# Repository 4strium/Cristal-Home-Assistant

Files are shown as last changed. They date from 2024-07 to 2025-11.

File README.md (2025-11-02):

<h1 align="center">Cristal Home Assistant</h1>

<p align="center">
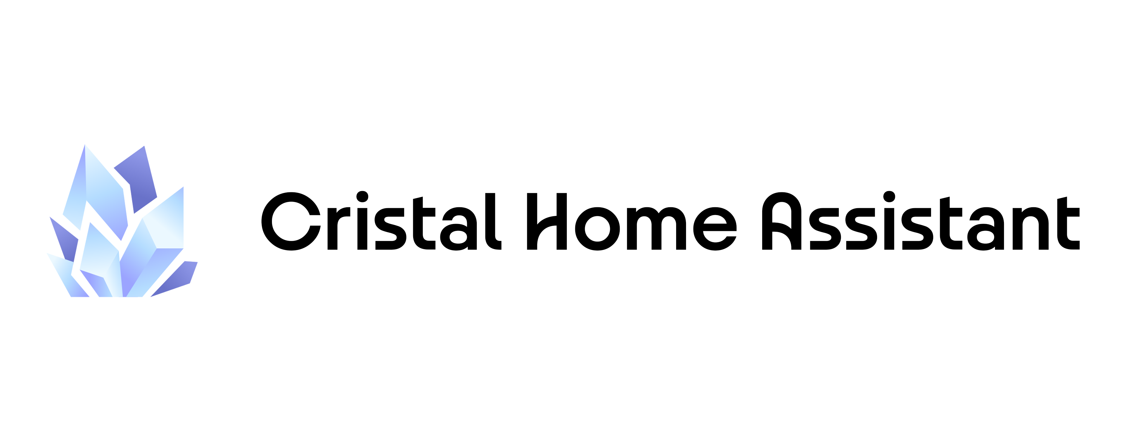
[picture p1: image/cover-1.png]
Cristal Home Assistant logo
  
</p>

## Introduction 
This personal project is based on a simple observation: nowadays there are a significant number of voice assistants coupled with numerous tools promising hyper connectivity and boosted productivity. We therefore end up getting lost in all these opaque layers processing our personal data as well as in subscriptions that are often prohibitively expensive compared to the simplicity of the tasks that we want our electronic companion to carry out.

<p align="center">
  Cristal Home Assistant
</p>

Today I decided to show you in the smallest details how I managed to design **Cristal** a voice assistant which can respond to all your wishes as long as you are ready to fiddle a minimum between the hardware and the software.

<p align="center">
  Cristal Home Assistant
</p>

## Project presentation

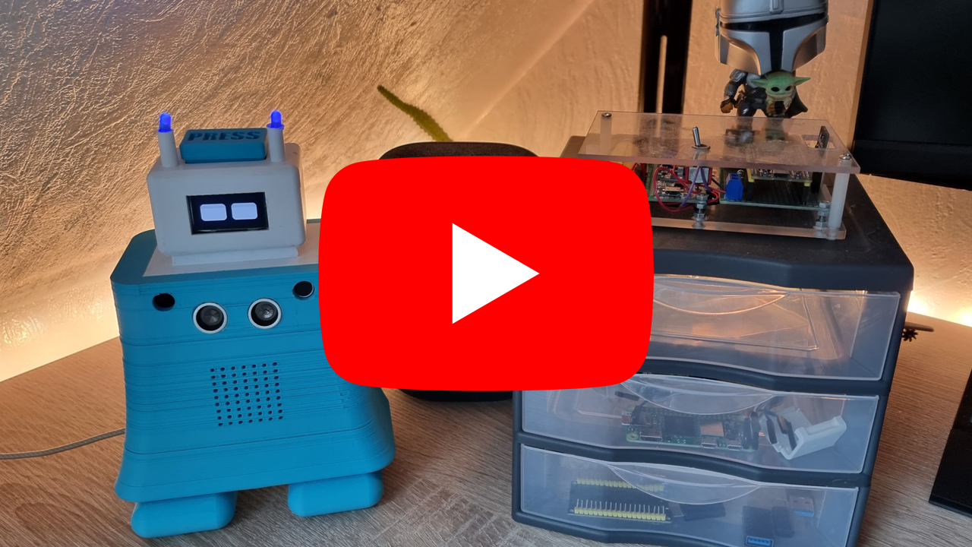
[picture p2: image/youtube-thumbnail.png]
(https://www.youtube.com/watch?v=M7OH803nQkw)


## The necessary equipment

<p align="center">
  
</p>

* An [ESP32](https://www.amazon.fr/esp32-wroom/s?k=esp32+wroom) will be the microcontroller of our project! We will take full advantage of its WiFi capacity but also of its integrated ADCs.

<p align="center">
  
</p>

* An [OLED screen (128x64) using the SH1106 chip](https://www.az-delivery.de/en/products/1-3zoll-i2c-oled-display), it will be the main means of feedback with the user.

<p align="center">
  
</p>

* A [MicroSD Card Module](https://www.amazon.fr/esp32-sd/s?k=esp32+sd) as well as a microSD card with the smallest capacity you have, in fact it will be useful to us only to temporarily store the audio file recorded by the microphone as well as the secret identifiers specific to your assistant, so it only takes a few kilobytes , but if you have personal upgrades requiring storage then judge the card's capacity accordingly. **⚠️ IMPORTANT NOTE : the card must be formatted in [FAT32 format](https://support.microsoft.com/fr-fr/topic/comment-convertir-un-lecteur-en-fat32-%C3%A0-l-aide-du-convertisseur-de-lecteur-5f751b9d-60a2-01bc-4079-2f536b876cc3)**

<p align="center">
  
</p>

*©TeachWithICT*

* An [Ultrasonic Sensor](https://www.amazon.com/ultrasonic-sensor/s?k=ultrasonic+sensor), **HC-SR04** is the safe bet.

<p align="center">
  
</p>

* A microphone using the i2s protocol, personally I use the [MAX9814](https://www.az-delivery.de/fr/products/max9814-mikrofon) which is widespread in the field of microelectronics in particular because it carries a high quality amplifier with automatic gain control (AGC) and low noise microphone polarization.

<p align="center">
  
</p>

* LED's of the color you want. *(the best is that it matches the color of your case)*

<p align="center">
  
</p>

* A [push button](https://www.amazon.fr/s?k=push+button&__mk_fr_FR=%C3%85M%C3%85%C5%BD%C3%95%C3%91&ref=nb_sb_noss). 

## A small server
Unfortunately, although the esp32 is a true marvel due to the extent of its capabilities, certain actions are either not possible, or possible but within a period of time which makes use uncomfortable and not smooth.

This is the case for voice recognition for example, which is therefore central to our project, which is why it is necessary to first record the audio file before transmitting it to a more powerful device so that the latter achieves recognition. But be careful by "more powerful" I don't mean a server with 32GB of ram and a premium CPU, no it's quite the opposite! You can either rent the smallest server configuration from a host, or use a Raspberry Pi at home.

<p align="center">
  
</p>

In my case for example, I rent a server thanks to DigitalOcean, I selected the lowest possible configuration with only 1GB of Ram and an inefficient Intel processor. But it is more than sufficient as you can see in the graphs below, in terms of the memory or processor usage percentages with actions initiated by my custom assistant.

<p align="center">
  
</p>

*Screenshot of data measured on the server I used for this project*

**If you would like to see in more detail how to set up your Linux server for the voice assistant and enable the [Google Assistant](https://assistant.google.com/intl/en_en/) SDK, [click here](https://mellaza.tech/posts/cristal-setup-server/).**

## 3D models for those who want/can print them...
You can print the four parts of the project, here are the 3d files, feel free to modify them as you wish! *(namely I printed it with my Ender-3 V3 SE)*

<p align="center">
  
</p>

* [The button to activate voice recording.](https://github.com/4strium/Cristal-Home-Assistant/blob/main/models/Bouton-Cristal-AI.3mf)
* [The head of the robot with its two antennas.](https://github.com/4strium/Cristal-Home-Assistant/blob/main/models/Head%20cristal.3mf)
* [The body that will carry all the electronics.](https://github.com/4strium/Cristal-Home-Assistant/blob/main/models/body.3mf) 
* [The hood to make the link between the head and the body.](https://github.com/4strium/Cristal-Home-Assistant/blob/main/models/capuchon.3mf)

## Wiring 

Make the connections follow this:

### Micro SD Card Module :
* 3.3 V
* MISO : GPIO 19
* CLK : GPIO 18
* MOSI : GPIO 23
* CS : GPIO 5
* GND

### Ultrasonic sensor :
* VCC : 5V
* Trig : GPIO 15
* Echo : GPIO 2
* GND

### OLED Display :
* VDD : 5V
* GND
* SCK : GPIO 22
* SDA : GPIO 27

### Blue LED'S :
* GPIO 12
* GND 

### Push Button :
* 3.3 V
* GPIO 4
* GND

### Microphone MAX9814 :
* VDD : 3.3 V
* OUT : GPIO 35 (ADC1_CHANNEL_7)
* GND

## Functionalities :

* If you want to see how to display live weather on screen via I2C, [click here](https://mellaza.tech/posts/live-weather-i2c-screen/).

* If you want to see how to display live date and time based on GPS coordinates (to get timezone) on an I2C screen, [click here](https://mellaza.tech/posts/date-time-i2c-screen/).

* If you want to see how to display daily news on screen via I2C, [click here](https://mellaza.tech/posts/live-news-i2c-screen/).

* If you want to see how to record sound on microSD card via MAX9814 microphone, [click here](https://mellaza.tech/posts/record-sound-max9814/).

* If you want to see how to keep your [API](https://en.wikipedia.org/wiki/API) identifiers secret for this ultra-connected project, [click here](https://mellaza.tech/posts/secure-credentials-esp32/).

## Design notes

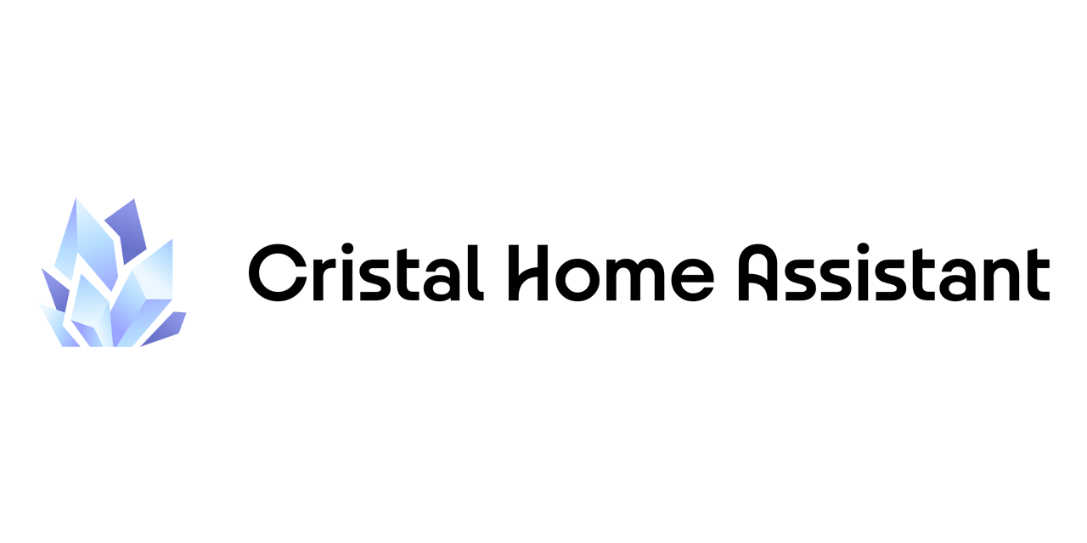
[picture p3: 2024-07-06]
image/cover-2.png

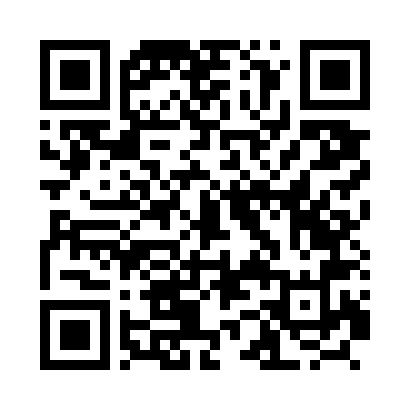
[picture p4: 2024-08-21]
image/qr.png

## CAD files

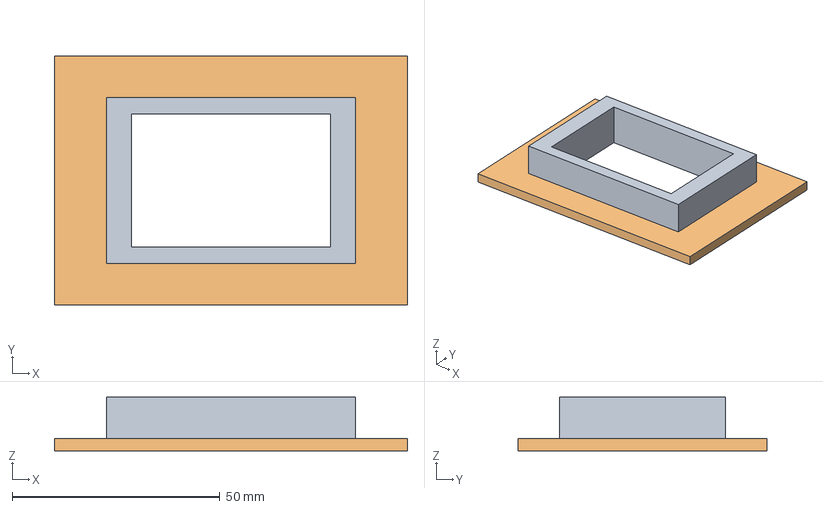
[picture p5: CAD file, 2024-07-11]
models/capuchon.3mf
85.0 x 60.0 x 13.0 mm
Corps_12
Corps_13

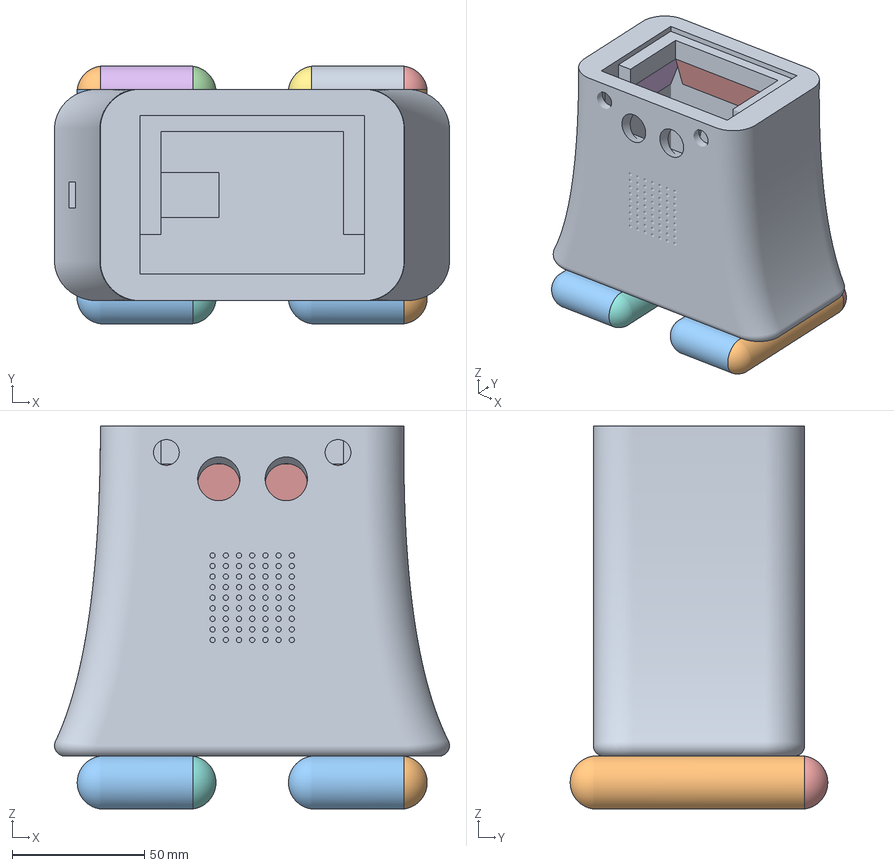
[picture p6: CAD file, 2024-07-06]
models/body.3mf
149.6 x 97.5 x 145.0 mm
main
Corps_03
Corps_01
Corps_03_(2)
Corps_03_(1)
Corps_03_(3)
Corps_03_(1)_(2)
Corps_02
Corps_03_(1)_(3)
Corps_02_(1)
Corps_01_(1)
Corps_16
Corps_15
Corps_14

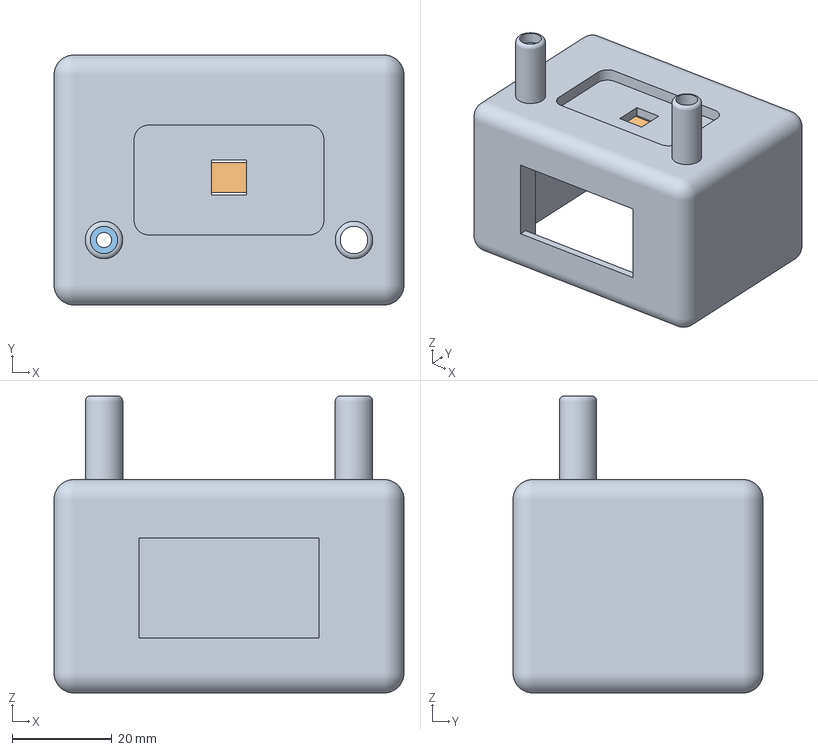
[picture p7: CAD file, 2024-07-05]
models/Head cristal.3mf
70.0 x 50.0 x 59.4 mm
Corps_01
Corps_02
Corps_03

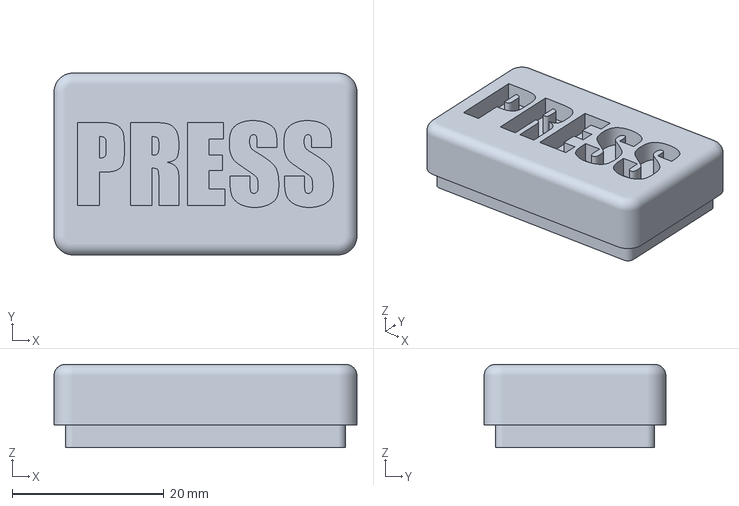
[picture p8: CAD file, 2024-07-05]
models/Bouton-Cristal-AI.3mf
40.0 x 24.0 x 11.0 mm

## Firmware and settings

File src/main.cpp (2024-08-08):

#include <Arduino.h>
#include <U8g2lib.h>
#include <stdio.h>
#include <Wire.h>
#include <pwm.h>
#include <open-meteo.h>
#include <WiFi.h>
#include <biticons.cpp>
#include <wavserv.h>
#include <rec-sound.h>
#include <date-heure.h> 
#include <gasdk.h>
#include <open-news-api.h>
#include <get_secret_values.h>

#define I2C_SDA 27
#define I2C_SCL 22
#define BLUE_LED 12
#define BTN_PIN 4
#define TRIG_PIN 15
#define ECHO_PIN 2
#define SOUND_SPEED 0.034
#define MAX_TITLES 5
#define DISPLAY_TIME 6000  // Temps d'affichage de chaque titre en millisecondes

U8G2_SH1106_128X64_NONAME_F_HW_I2C u8g2(U8G2_R2, /* reset=*/ U8X8_PIN_NONE);

// Variables :
char input_refl;
char input;

long duration;
float distanceCm;

int count_inactivity = 0;
bool actived = false;
int passive_counter = 0;

String API_key;
String Device_Id;
String Model_Id;

String* titles_news = nullptr;

class Eyes {
private :
  int x1, x2, y, width, height;
public :
  int step;
  void initialize(){
    x1 = 8;
    x2 = 70;
    y = 24;
    height = 14;
    width = 50;
    step = 0;
  }

  void det_eyes_in(){
    for (int brightness = 0; brightness < 256; brightness+=15){
      u8g2.clearBuffer();
      u8g2.setContrast(brightness);
      u8g2.drawRBox(x1, y, width, height, 7);
      u8g2.drawRBox(x2, y, width, height, 7);
      u8g2.sendBuffer();
    }
    step = 1;
  }

  void det_eyes_out(){
    for (int brightness = 255; brightness >= 0; brightness-=15){
      u8g2.clearBuffer();
      u8g2.setContrast(brightness);
      u8g2.drawRBox(x1, y, width, height, 7);
      u8g2.drawRBox(x2, y, width, height, 7);
      u8g2.sendBuffer();
    }
    step = 0;
  }

  void clign_in(){
    if (step == 2){ 
      for (int i = 0; i < 12; i++){
        u8g2.clearBuffer();
        u8g2.drawRBox(x1, y, width, height, 7);
        u8g2.drawRBox(x2, y, width, height, 7);
        u8g2.sendBuffer();
        y += 1;
        height -= 2;
      };
      step = 1;
    }
  } 

  void clign_out(){
    if (step == 1){
      for (int i = 0; i < 12; i++){
        u8g2.clearBuffer();
        u8g2.drawRBox(x1, y, width, height, 7);
        u8g2.drawRBox(x2, y, width, height, 7);
        u8g2.sendBuffer();
        y -= 1;
        height += 2;
      };
      step = 2;
    }
  }

/*
  void round_in(){
    if (step == 0){
      for (int i = 0; i < 16; i++){
        u8g2.clearBuffer();
        u8g2.drawRBox(x1, y, width, height, 7);
        u8g2.drawRBox(x2, y, width, height, 7);
        u8g2.sendBuffer();
        y += 1;
        height -= 1;
        x1 += 1;
        x2 += 1;
        width -= 2;
      };
      step = 2;
    }
  }

  void round_out(){
    if (step == 2){
      for (int i = 0; i < 16; i++){
        u8g2.clearBuffer();
        u8g2.drawRBox(x1, y, width, height, 7);
        u8g2.drawRBox(x2, y, width, height, 7);
        u8g2.sendBuffer();
        y -= 1;
        height += 1;
        x1 -= 1;
        x2 -= 1;
        width += 2;
      };
      step = 0;
      digitalWrite(BLUE_LED, LOW);
    }
  }

  void look_right(){
    if (step == 2){
      for (int i = 0; i < 14; i++){
        u8g2.clearBuffer();
        u8g2.drawRBox(x1, y, width, height, 7);
        u8g2.drawRBox(x2, y, width, height, 7);
        u8g2.sendBuffer();
        x1 += 4;
        x2 += 1;
      }
      delay(1000);
      for (int i = 0; i < 14; i++){
        u8g2.clearBuffer();
        u8g2.drawRBox(x1, y, width, height, 7);
        u8g2.drawRBox(x2, y, width, height, 7);
        u8g2.sendBuffer();
        x1 -= 4;
        x2 -= 1;
      }
    }
  }

  void look_left(){
    if (step == 2){
      for (int i = 0; i < 14; i++){
        u8g2.clearBuffer();
        u8g2.drawRBox(x1, y, width, height, 7);
        u8g2.drawRBox(x2, y, width, height, 7);
        u8g2.sendBuffer();
        x1 -= 1;
        x2 -= 4;
      }
      delay(1000);
      for (int i = 0; i < 14; i++){
        u8g2.clearBuffer();
        u8g2.drawRBox(x1, y, width, height, 7);
        u8g2.drawRBox(x2, y, width, height, 7);
        u8g2.sendBuffer();
        x1 += 1;
        x2 += 4;
      }
    }
  }

  void look_up(){
    if (step == 2){ 
      for (int i = 0; i < 20; i++){
        u8g2.clearBuffer();
        u8g2.drawRBox(x1, y, width, height, 7);
        u8g2.drawRBox(x2, y, width, height, 7);
        u8g2.sendBuffer();
        x1 += 1;
        x2 -= 1;
        y -= 1;
      }
      delay(1000);
      for (int i = 0; i < 20; i++){
        u8g2.clearBuffer();
        u8g2.drawRBox(x1, y, width, height, 7);
        u8g2.drawRBox(x2, y, width, height, 7);
        u8g2.sendBuffer();
        x1 -= 1;
        x2 += 1;
        y += 1;
      }
    }
  }

  void look_down(){
    if (step == 2){
      for (int i = 0; i < 20; i++){
        u8g2.clearBuffer();
        u8g2.drawRBox(x1, y, width, height, 7);
        u8g2.drawRBox(x2, y, width, height, 7);
        u8g2.sendBuffer();
        x1 += 1;
        x2 -= 1;
        y += 1;
      }
      delay(1000);
      for (int i = 0; i < 20; i++){
        u8g2.clearBuffer();
        u8g2.drawRBox(x1, y, width, height, 7);
        u8g2.drawRBox(x2, y, width, height, 7);
        u8g2.sendBuffer();
        x1 -= 1;
        x2 += 1;
        y -= 1;
      }
    }
  }
*/
};

class Meteo_aff {
  public :
  int wmo_code, dn_cond;
  float temp;
  mutable const char* location;

  void print_4user(){
    u8g2.clearBuffer();
    u8g2.setFont(u8g2_font_helvB18_te);
    u8g2.setFontDirection(2);
    u8g2.enableUTF8Print();
    char buffer_te[8];
    snprintf(buffer_te, sizeof(buffer_te), "%.1f°C", temp);
    u8g2.drawUTF8(70,5,buffer_te);

    u8g2.setFont(u8g2_font_helvB14_te);
    u8g2.drawUTF8(125,40,location);

    u8g2.setBitmapMode(1);

    if (wmo_code == 0 && dn_cond == 1){
      u8g2.drawXBM(85, 2, 32, 32, epd_bitmap_soleil);
    }
    else if ((wmo_code == 0 || wmo_code == 1 || wmo_code == 2) && dn_cond == 0){
      u8g2.drawXBM(85, 2, 32, 32, epd_bitmap_lune);
    }
    else if ((wmo_code == 1 || wmo_code == 2) && dn_cond == 1){
      u8g2.drawXBM(85, 2, 32, 32, epd_bitmap_ciel_clair);
    }
    else if (wmo_code == 3){
      u8g2.drawXBM(85, 2, 32, 32, epd_bitmap_nuage);
    }
    else if (wmo_code == 45 || wmo_code == 48 || wmo_code == 51 || wmo_code == 53 || wmo_code == 55 || wmo_code == 56 || wmo_code == 57){
      u8g2.drawXBM(85, 2, 32, 32, epd_bitmap_brumeux);
    }
    else if (wmo_code == 61 || wmo_code == 63 || wmo_code == 65 || wmo_code == 66 || wmo_code == 67 || wmo_code == 80 || wmo_code == 81 || wmo_code == 82){
      u8g2.drawXBM(85, 2, 32, 32, epd_bitmap_pluie_abondante);
    }
    else if (wmo_code == 71 || wmo_code == 73 || wmo_code == 75 || wmo_code == 77 || wmo_code == 85 || wmo_code == 86){
      u8g2.drawXBM(85, 2, 32, 32, epd_bitmap_flocon_de_neige);
    }
    else if (wmo_code == 95 || wmo_code == 96 || wmo_code == 99){
      u8g2.drawXBM(85, 2, 32, 32, epd_bitmap_orage);
    }

    u8g2.sendBuffer();
    u8g2.setFontDirection(0);
  }

  void setLocation(const char* newLocation) const {
    location = newLocation;
  }
};

class Timer {
  private :
    int requ_time, minutes, secondes;
    bool already_act;

    void set_normal_time(void){
      if (requ_time >= 60){
        minutes = requ_time / 60;
        secondes = requ_time - (minutes*60);
      }
      else{
        minutes = 0;
        secondes = requ_time;
      }
    }

    void start_timer(void){
      if (!already_act){
        already_act = true;
        char buffer_time_curr[5];
        while (requ_time > 0){
          u8g2.clearBuffer();
          u8g2.setFont(u8g2_font_helvB18_te);
          u8g2.setFontDirection(2);
          u8g2.enableUTF8Print();
          u8g2.drawUTF8(65,40,"Timer");

          u8g2.setFont(u8g2_font_logisoso24_tr);

          snprintf(buffer_time_curr, sizeof(buffer_time_curr), "%i:%02i", minutes, secondes);
          u8g2.drawUTF8(65,5,buffer_time_curr);

          u8g2.setBitmapMode(1);
          if (requ_time % 4 == 0){
            u8g2.drawXBM(66, 2, 64, 64, epd_bitmap_sablier_top);
          }
          else if (requ_time % 4 == 1){
            u8g2.drawXBM(66, 2, 64, 64, epd_bitmap_sablier_left);
          }
          else if (requ_time % 4 == 2){
            u8g2.drawXBM(66, 2, 64, 64, epd_bitmap_sablier_bottom);
          }
          else {
            u8g2.drawXBM(70, 2, 64, 64, epd_bitmap_sablier_right);
          }

          requ_time--;
          u8g2.sendBuffer();
          set_normal_time();
          delay(1000);
        }       
      }
    }
  public :
    Timer(int inp_t){
      requ_time = inp_t;
      already_act = false;
      set_normal_time();
      start_timer();
    }
};

void bonjour_func(){
  for (int i=0;i<25;i++){
    u8g2.clearBuffer();
    u8g2.setFont(u8g2_font_helvB18_te);
    u8g2.setFontDirection(2);
    u8g2.enableUTF8Print();

    u8g2.setFont(u8g2_font_lubB14_tr);
    u8g2.drawUTF8(110,45,"Bonjour !");

    u8g2.setBitmapMode(1);
    
    if (i % 2 == 0){
      u8g2.drawXBM(50, 2, 32, 32, epd_bitmap_smiley);
    }
    else {
      u8g2.drawXBM(50, 2, 32, 32, epd_bitmap_sourire);
    }
    u8g2.sendBuffer();
    delay(300);
  }
}

void print_datetime(){
  u8g2.clearBuffer();
  u8g2.setFontDirection(2);
  u8g2.enableUTF8Print();

  u8g2.setFont(u8g2_font_logisoso20_tr);
  String timec = get_time();
  u8g2.drawUTF8(96,30,timec.c_str());

  u8g2.setFont(u8g2_font_logisoso18_tr);
  String date = get_date();
  u8g2.drawUTF8(120,2,date.c_str());

  u8g2.sendBuffer();
  delay(8000);
}

float get_distance_ultrasonic(){
  // Clears the trigPin
  digitalWrite(TRIG_PIN, LOW);
  delayMicroseconds(2);
  // Sets the trigPin on HIGH state for 10 micro seconds
  digitalWrite(TRIG_PIN, HIGH);
  delayMicroseconds(10);
  digitalWrite(TRIG_PIN, LOW);
  
  // Reads the echoPin, returns the sound wave travel time in microseconds
  duration = pulseIn(ECHO_PIN, HIGH);
  
  // Calculate the distance
  float distanceCm = duration * SOUND_SPEED/2;
  return distanceCm;
}

void display_titles() {
    // Obtenir le tableau de titres
    if (titles_news == nullptr){
      titles_news = get_five_top_news();
    }

    u8g2.clearBuffer();
    u8g2.setFlipMode(1); // Activer le mode de retournement pour inverser l'affichage
    u8g2.setFontDirection(0);
    u8g2.enableUTF8Print();
    u8g2.setFont(u8g2_font_ncenB08_tf);

    // Constante pour la largeur de l'écran en pixels
    const int screenWidth = 128; // Largeur de l'écran OLED

    for (int i = 0; i < MAX_TITLES; i++) {
        u8g2.clearBuffer(); // Effacer le tampon de l'écran
        u8g2.setCursor(0, 10); // Position du curseur pour le texte

        // Préparer le titre avec le préfixe "Titre X: "
        String fullTitle = "Titre " + String(i + 1) + ": " + titles_news[i];
        
        // Variables pour gérer les lignes et l'espacement vertical
        int lineHeight = 10; // Hauteur de ligne (ajustez selon la taille de police)
        int yPosition = 10;  // Position initiale en Y

        // Variable pour stocker la largeur courante du texte
        int currentWidth = 0;

        // Diviser le texte en mots pour gérer le retour à la ligne
        char *token = strtok((char *)fullTitle.c_str(), " ");
        while (token != nullptr) {
            String word = String(token) + " ";
            int wordWidth = u8g2.getStrWidth(word.c_str());

            if (currentWidth + wordWidth > screenWidth) {
                // Si le mot ne tient pas sur la ligne actuelle, aller à la ligne suivante
                yPosition += lineHeight;
                u8g2.setCursor(0, yPosition);
                currentWidth = 0;
            }

            // Imprimer le mot courant et mettre à jour la largeur actuelle
            u8g2.print(word);
            currentWidth += wordWidth;

            // Passer au mot suivant
            token = strtok(nullptr, " ");
        }

        u8g2.sendBuffer(); // Envoyer le tampon à l'écran
        delay(DISPLAY_TIME); // Attendre avant d'afficher le titre suivant
    }
    u8g2.setFlipMode(0); // désactiver le mode de retournement pour inverser l'affichage
}

Eyes e1;

void setup(void) {
  pinMode(35,INPUT);
  Serial.begin(9600);
  Wire.begin(I2C_SDA, I2C_SCL);
  u8g2.begin();
  e1.initialize();

  pinMode(TRIG_PIN, OUTPUT);
  pinMode(ECHO_PIN, INPUT);

  pinMode(BLUE_LED, OUTPUT);

  pinMode(BTN_PIN, INPUT);

  const char* ssid = get_secret(0);
  const char* password = get_secret(1);
  API_key = get_secret(2);
  Model_Id = get_secret(3);
  Device_Id = get_secret(4);

  // Utilisation des valeurs
  Serial.println("SSID: " + String(ssid));
  Serial.println("Password: " + String(password));

  Serial.println("Connexion au réseau WiFi...");
  WiFi.begin(ssid, password);

  while (WiFi.status() != WL_CONNECTED) {
    delay(1000);
    Serial.println("Connexion en cours...");
  }

  Serial.println("Connecté au réseau WiFi !");

}

void loop(void) {

  count_inactivity++;
  float dist = get_distance_ultrasonic();
  
  if (dist < 15.0)
  {
    count_inactivity--;

    e1.det_eyes_in();
    actived = true;

    while (digitalRead(BTN_PIN) == LOW) {
      float dist = get_distance_ultrasonic();

      if ((dist > 15.0)&&(passive_counter >= 20)){
        passive_counter = 0;
        break;
      }
      else if (dist > 15.0){passive_counter++;}
      delay(300);
    }

    if (digitalRead(BTN_PIN) == HIGH)
    {
      if (e1.step == 1)
      {
        xTaskCreate([](void *parameter)
        {
          e1.clign_out();
          vTaskDelete(NULL); 
        }, "task1", 2048, NULL, 5, NULL);
        xTaskCreate([](void *parameter)
        {
          vari_blue(parameter);
          vTaskDelete(NULL); 
        }, "task2", 2048, NULL, 5, NULL);
      }
      delay(500);
      record_mic();
      delay(500);
      String word = recowav();
      Serial.println(word);
      if (word == String("météo"))
        {
          Meteo_aff m1;
          m1.temp =  get_temp();
          m1.dn_cond = get_day_night();
          m1.wmo_code = get_WMO();
          m1.setLocation("Guilers");
          m1.print_4user();
          delay(10000);
        }
      else if (word == String("minuteur"))
        {
          Timer(600);
        }
      else if (word == String("bonjour"))
        {
          bonjour_func();
        }
      else if ((word == String("date"))||(word == String("heure")||(word == String("jour"))))
        {
          print_datetime();
        }
      else if (word == String("allume bureau"))
        {
          String input_phrase = String("Turn on Bureau Romain");
          exec_com_assistant(API_key,Device_Id,Model_Id,input_phrase);
        }
      else if (word == String("éteins bureau"))
        {
          String input_phrase = String("Turn off Bureau Romain");
          exec_com_assistant(API_key,Device_Id,Model_Id,input_phrase);
        }
      else if (word == String("ouvre le volet"))
        {
          String input_phrase = String("set velux romain at 100%");
          exec_com_assistant(API_key,Device_Id,Model_Id,input_phrase);
        }
      else if (word == String("entrouvre le volet"))
        {
          String input_phrase = String("set velux romain at 50%");
          exec_com_assistant(API_key,Device_Id,Model_Id,input_phrase);
        }
      else if (word == String("ferme le volet"))
        {
          String input_phrase = String("set velux romain at 0%");
          exec_com_assistant(API_key,Device_Id,Model_Id,input_phrase);
        }
      else if (word == String("TF1"))
        {
          String input_phrase = String("tf1");
          exec_com_assistant(API_key,Device_Id,Model_Id,input_phrase);
        }
      else if (word == String("France 2"))
        {
          String input_phrase = String("france 2");
          exec_com_assistant(API_key,Device_Id,Model_Id,input_phrase);
        }
      else if (word == String("M6"))
        {
          String input_phrase = String("m6");
          exec_com_assistant(API_key,Device_Id,Model_Id,input_phrase);
        }
      else if (word == String("France 3"))
        {
          String input_phrase = String("france 3");
          exec_com_assistant(API_key,Device_Id,Model_Id,input_phrase);
        }
      else if (word == String("info")||word == String("infos"))
        {
          display_titles();
        }
    }

    if (e1.step == 2)
    {
      delay(1000);
      xTaskCreate([](void *parameter)
      {
        e1.clign_in();
        vTaskDelete(NULL); 
      }, "task1", 2048, NULL, 5, NULL);
      xTaskCreate([](void *parameter)
      {
        fade_out_blue(parameter);
        vTaskDelete(NULL); 
      }, "task2", 2048, NULL, 5, NULL);
    }

    delay(2000);

  }

  if (count_inactivity >= 20){
    if (actived){
      e1.det_eyes_out();
      actived = false;
    }
    count_inactivity = 0;
  }

  delay(300);
}

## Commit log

2024-07-05 Cloning a private repo, recovering previous work without leaking credentials
    [Bouton-Cristal-AI.3mf, Head cristal.3mf, body.3mf]
2024-07-08 Update button pin configuration from analogic to digital
2024-07-10 Update WiFi and SD card libraries, fix SPI pin configuration, and send audio file over WiFi
    [main.cpp]
2024-07-11 Ajout du cou modélisé
    [capuchon.3mf]
2024-07-11 Added wavserver librairy based on previous code, and fixed wiring
    [main.cpp]
2024-07-12 Increase buffer size fand trying to solve some issues
    [main.cpp]
2024-07-15 Ajout de l'écriture des headers pour le fichier wav, pour obtenir un fichier sain.
2024-07-15 Quelques modifications dans la bibliothèque d'enregistrement de fichier audio
2024-07-15 Ajout d'un filtre médian pour améliorer la qualité audio
2024-07-29 Fix WAV file header calculation bug & ADC sampler
2024-08-02 Fix WAV file bug & ADC Built-in sampler
    [main.cpp]
2024-08-02 Remove debug print statement, fix Eyes screen system
    [main.cpp]
2024-08-03 Fixed issues with eyes on display and removed unused variables, functions, and print debug
    [main.cpp]
2024-08-05 Add Google Assistant SDK support from esp32
2024-08-05 Update Google Assistant SDK headers and fix API key conversion
    [main.cpp]
